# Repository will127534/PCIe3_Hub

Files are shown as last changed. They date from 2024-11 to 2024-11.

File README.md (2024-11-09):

# RPI5 PCIe 3.0 Hub
An opensource PCIe 3.0 Hub design based on ASM2806 with Raspberry Pi 5's PCIe FPC connector design

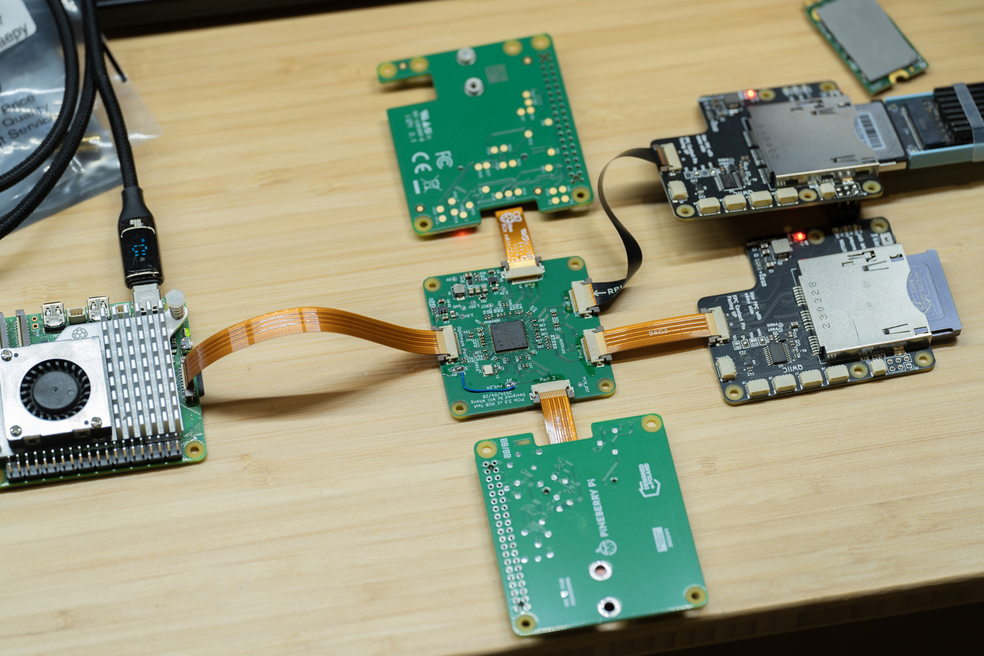
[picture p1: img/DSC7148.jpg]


## Important note

ASM2806A != ASM2806, this design is using ASM2806 specifically.

## Introduction

So basically this is the follow-up on [this](https://www.willwhang.dev/Solar-eclipse-2024/#pcie-30-hub-development), that I finally found a schematic containing how to use [ASM2806](https://www.asmedia.com.tw/product/012Yq70sX2zI9xN5/7c5YQ79xz8urEGr1), which is a PCIe 3.0 hub with x2 upstream and four x1 downstream.  

The board is designed to give that schematic a try, so it is not really designed like those PCIe 2.0 NVMe hub RPi hat designs you might have seen before. Its design is to make my life easier when debugging/soldering it. (i.e single sided components + 5cm x 5cm board size).

Also, because I'm going to build a few boards for RPi5 that I want to have a PCIe 3.0 hub with, all the PCIe connectors on board are the same as RPi’s PCIe FPC "[standard](https://datasheets.raspberrypi.com/pcie/pcie-connector-standard.pdf)", and the testing is also done on RPi5.

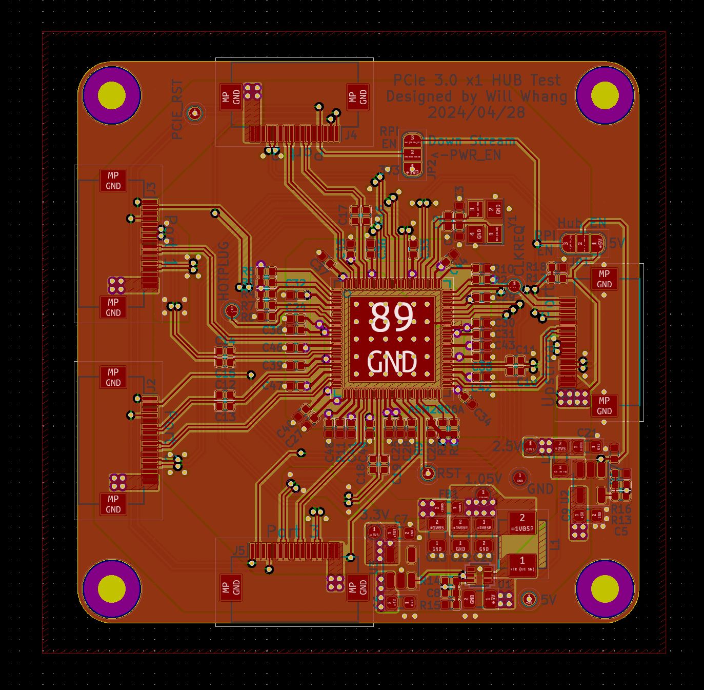
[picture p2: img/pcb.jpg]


Is it working? Yeap!

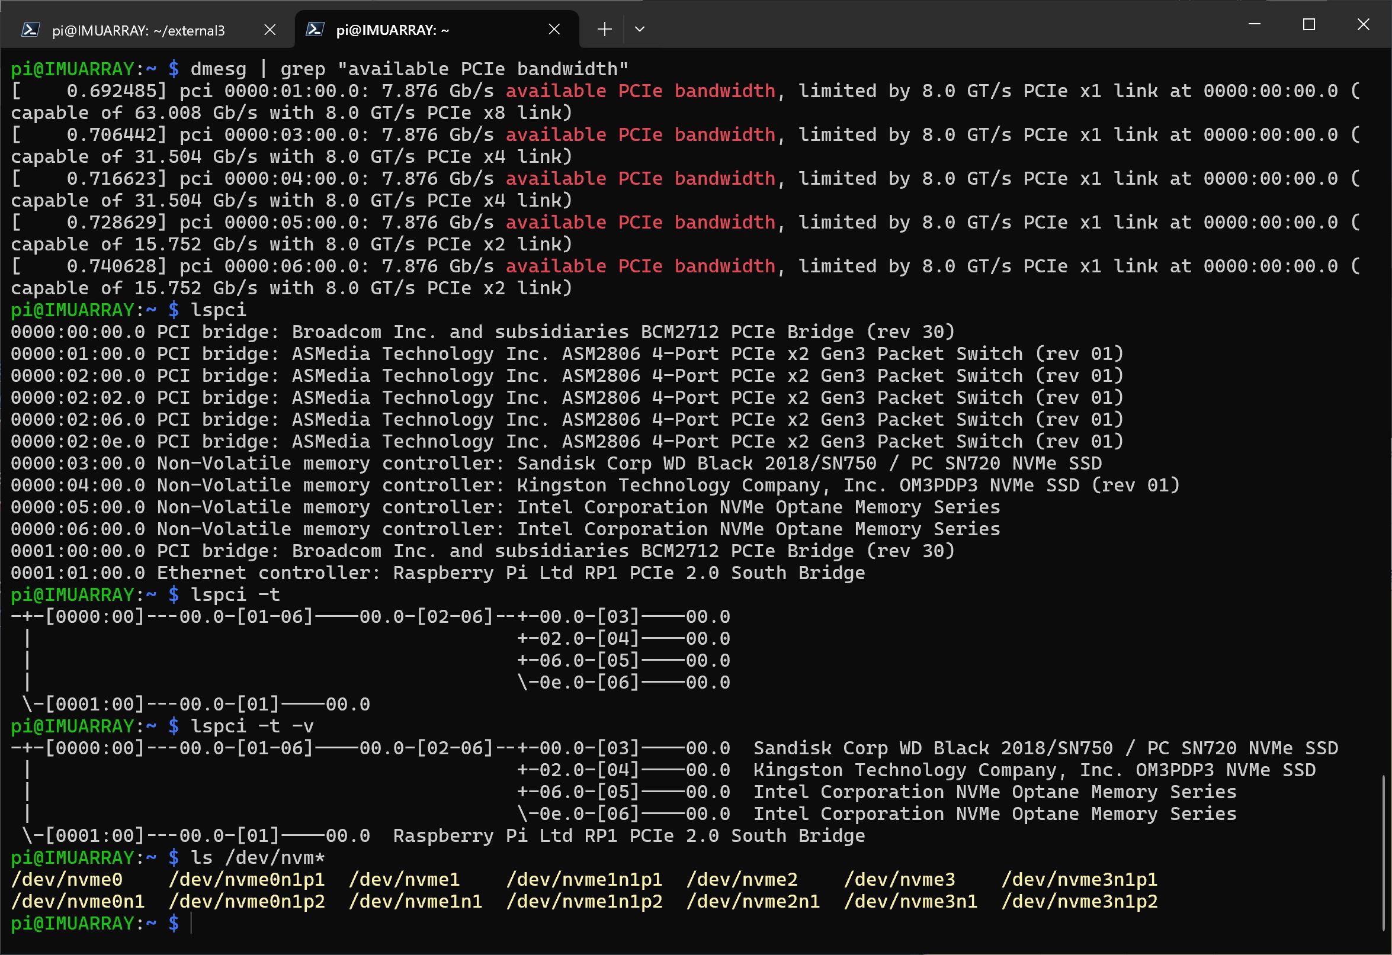
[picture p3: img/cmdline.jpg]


## Detailed notes

So if you compare the PCB files here and the one in the photo, you can see that there is a jump wire in the photo. At the same time, if you look at the PCB files, there are two jumper JP1 and JP2. This is because RPI5 FPC has a power enable signal, where the device should use this signal to power down and up. However, this makes the debugging (checking rail voltage) process slightly difficult, so the jumper here is for forcing ASM2806/downstream device power on. JP1 is for ASM2806 power enable signal, either connect it directly to 5V or using the RPI enable signal. JP2 is the downstream PCIe FPC power enable signal, and it is either 3.3V or RPI enable signal. The one shown in the photo has the downstream PCIe FPC power enable signal bodge wired to the RPI enable signal, and that has been fixed in the PCB file here on GitHub.

For ASM2806, it is configured as four downstream ports with each getting x1 PCIe 3.0. Both upstream clock and downstream clock are based on 100Mhz PCIe clock. No SPI flash is required to function (thankfully). It requires three voltages: 3.3V/2.5V/1.05V. Most of the DC-DC converter here is just grabbing the design/parts I have on my hand and are overspec a bit so you can change it for sure. For the rail naming, there is also 3.3V suspend, but I connected it to 3.3V directly, and the 1.05V I'm following the schematic to add some filtering.

Surprisingly, it doesn't take that much power. As you can see in the power consumption table in the schematic, I can stress test without a heatsink for hours, but the chip does get hot to touch. If that worries you, then you might have to consider adding a small heatsink, especially if the PCB copper is not large enough to dissipate the heat.

There are some signals that I'm interested in, specifically the HOTPLUG signal, and it is attached to a test pad, but I'm not able to see it function by pulling this pin up or down.

Finally, the thing that caught me during the test is how the schematic connects the crystal. In the schematic, there is a 10pf cap on the XO/XI pins, which I'm still quite puzzled about (Normally, I expect to see like a 1M ohm resistor across for the Crystal driver), but it is necessary to have this chip work.

## Performance

Yes, each PCIe downstream device independently can consume up to PCIe 3.0 x1 speed, but once you have more than one going, I’m surprised the bandwidth doesn't seem to be equally shared. I'm not quite sure if that is caused by the tool I use to stress test (four NVMe drives + FIO), or is it caused by the NVMe drive itself (maximum supported MPS). Following Jeff Geerling's [guide](https://www.jeffgeerling.com/blog/2021/getting-faster-10-gbps-ethernet-on-raspberry-pi) I've also enabled pci=pcie_bus_perf and the hub can support up to 512 byte MPS also:

```
[    0.752521] pci 0000:00:00.0: Max Payload Size set to  512/ 512 (was  128), Max Read Rq  512
[    0.752532] pci 0000:01:00.0: Max Payload Size set to  512/ 512 (was  128), Max Read Rq  512
[    0.752543] pci 0000:02:00.0: Max Payload Size set to  512/ 512 (was  128), Max Read Rq  512
[    0.752558] pci 0000:03:00.0: Max Payload Size set to  512/ 512 (was  128), Max Read Rq  512
[    0.752568] pci 0000:02:02.0: Max Payload Size set to  512/ 512 (was  128), Max Read Rq  512
[    0.752588] pci 0000:04:00.0: Max Payload Size set to  128/ 128 (was  128), Max Read Rq  128
[    0.752598] pci 0000:02:06.0: Max Payload Size set to  512/ 512 (was  128), Max Read Rq  512
[    0.752616] pci 0000:05:00.0: Max Payload Size set to  256/ 256 (was  128), Max Read Rq  256
[    0.752627] pci 0000:02:0e.0: Max Payload Size set to  512/ 512 (was  128), Max Read Rq  512
[    0.752644] pci 0000:06:00.0: Max Payload Size set to  256/ 256 (was  128), Max Read Rq  256
```

## Footnotes
* [Interactive BOM](https://htmlpreview.github.io/?https://github.com/will127534/PCIe3_Hub/blob/main/bom/ibom.html) [(provided by InteractiveHtmlBom)
](https://github.com/openscopeproject/InteractiveHtmlBom)
* designed with Kicad v8.0
* Please refrain from inquiring about the source of the chip. Additionally, please note that this chip is quite expensive (approximately 15-20 USD), which is one of the reasons why you may not have encountered any PCIe 3.0 hubs for RPi5 other than this one.

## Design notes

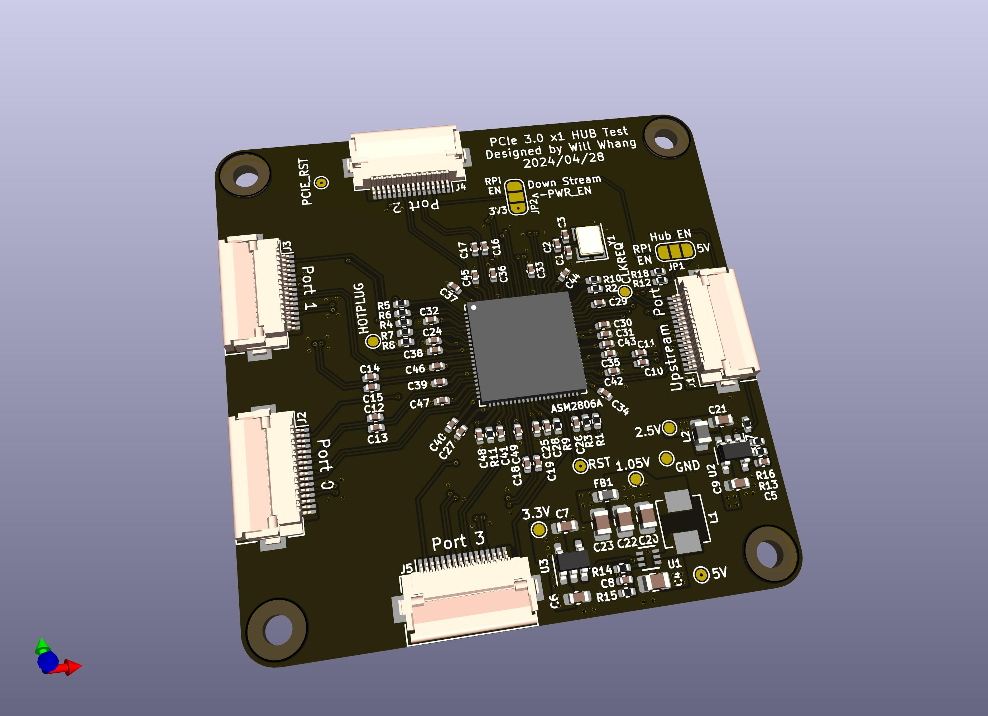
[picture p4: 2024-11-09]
img/3d.jpg

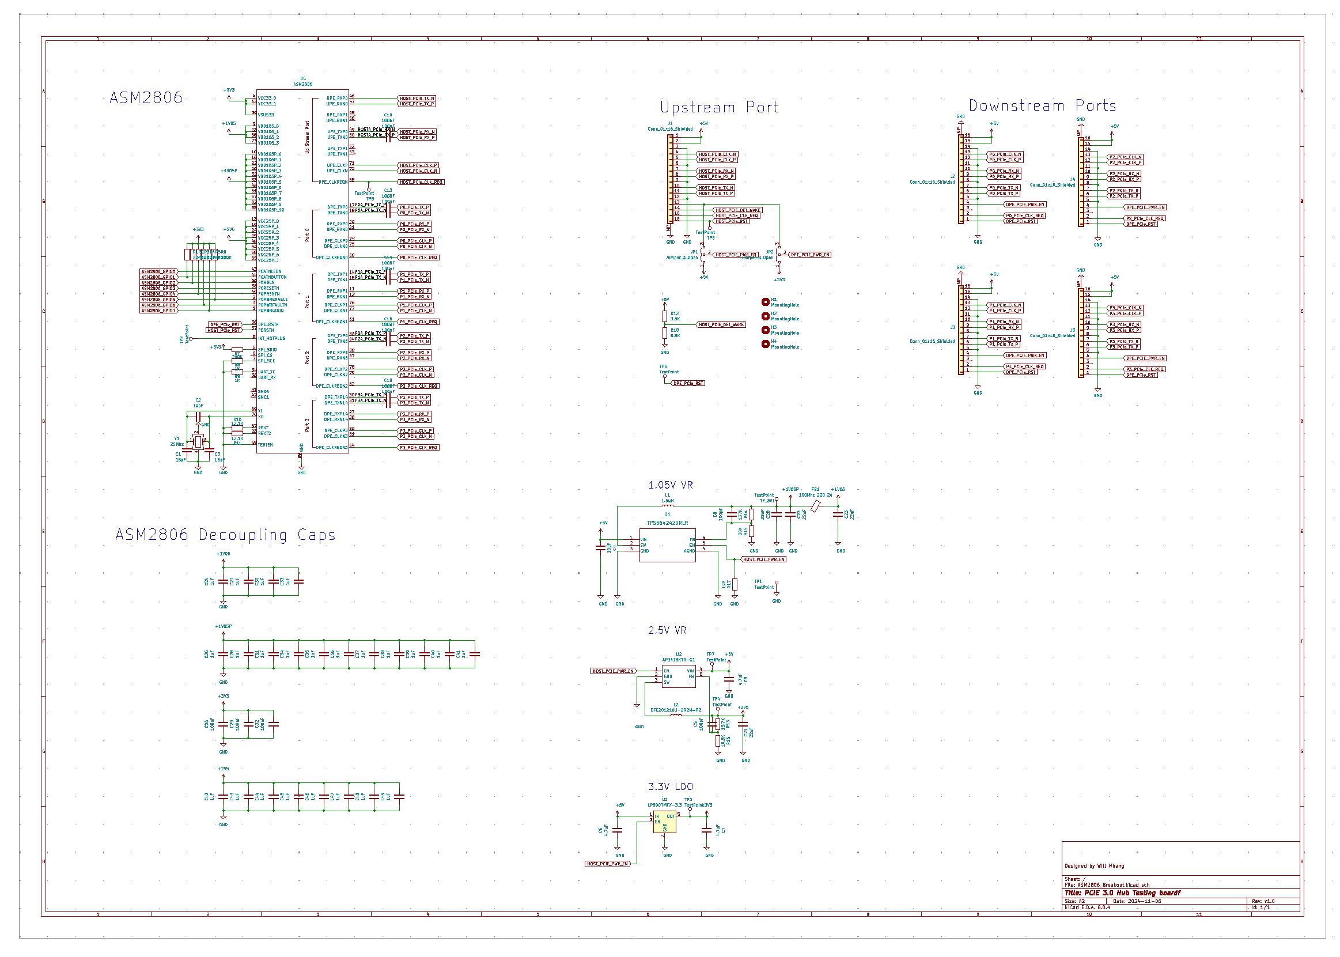
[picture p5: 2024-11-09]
img/sch.jpg

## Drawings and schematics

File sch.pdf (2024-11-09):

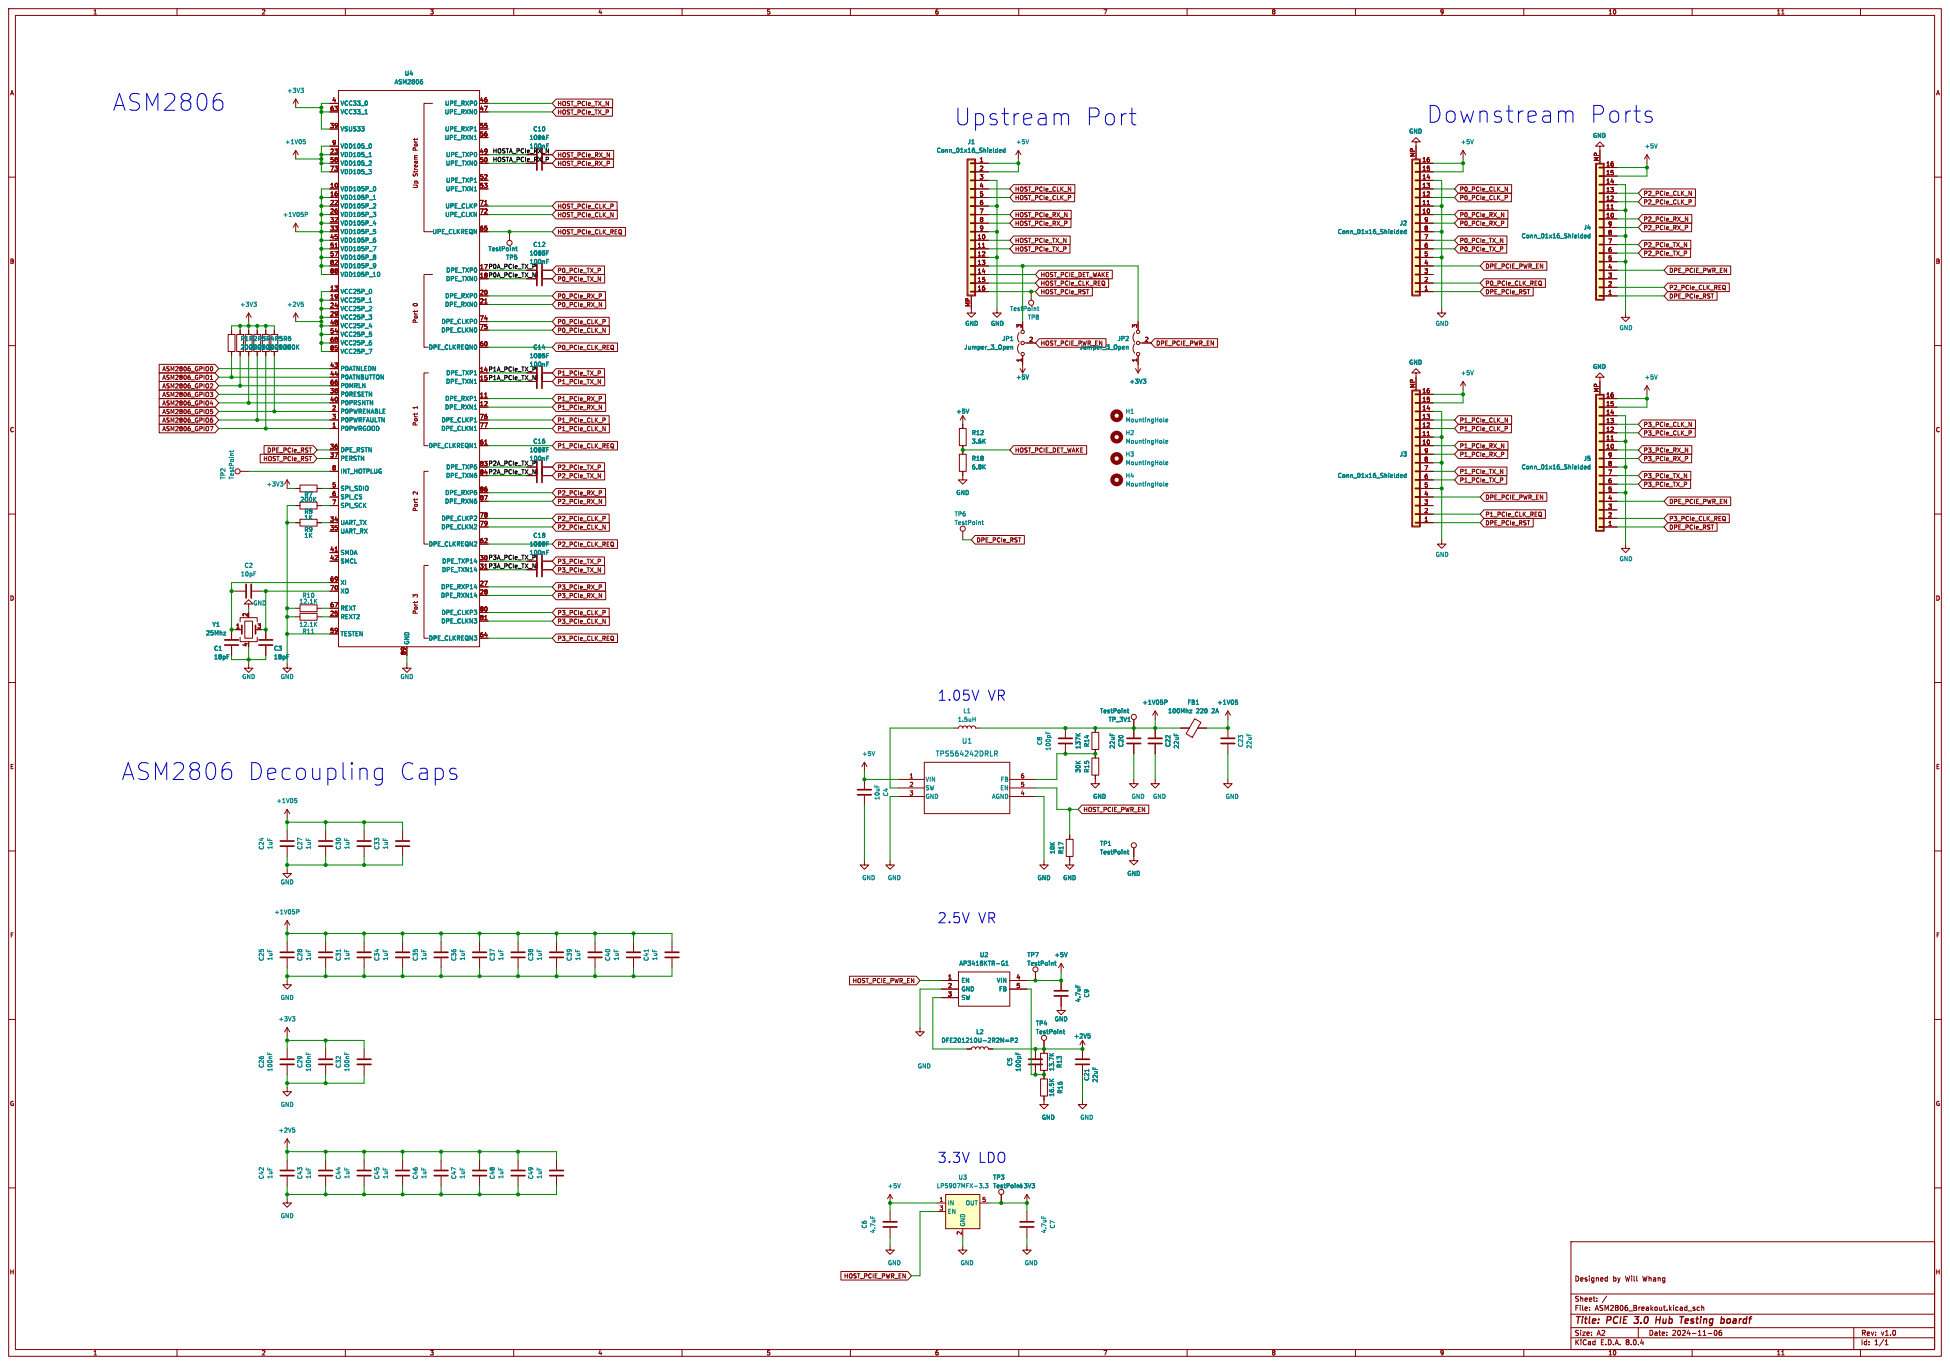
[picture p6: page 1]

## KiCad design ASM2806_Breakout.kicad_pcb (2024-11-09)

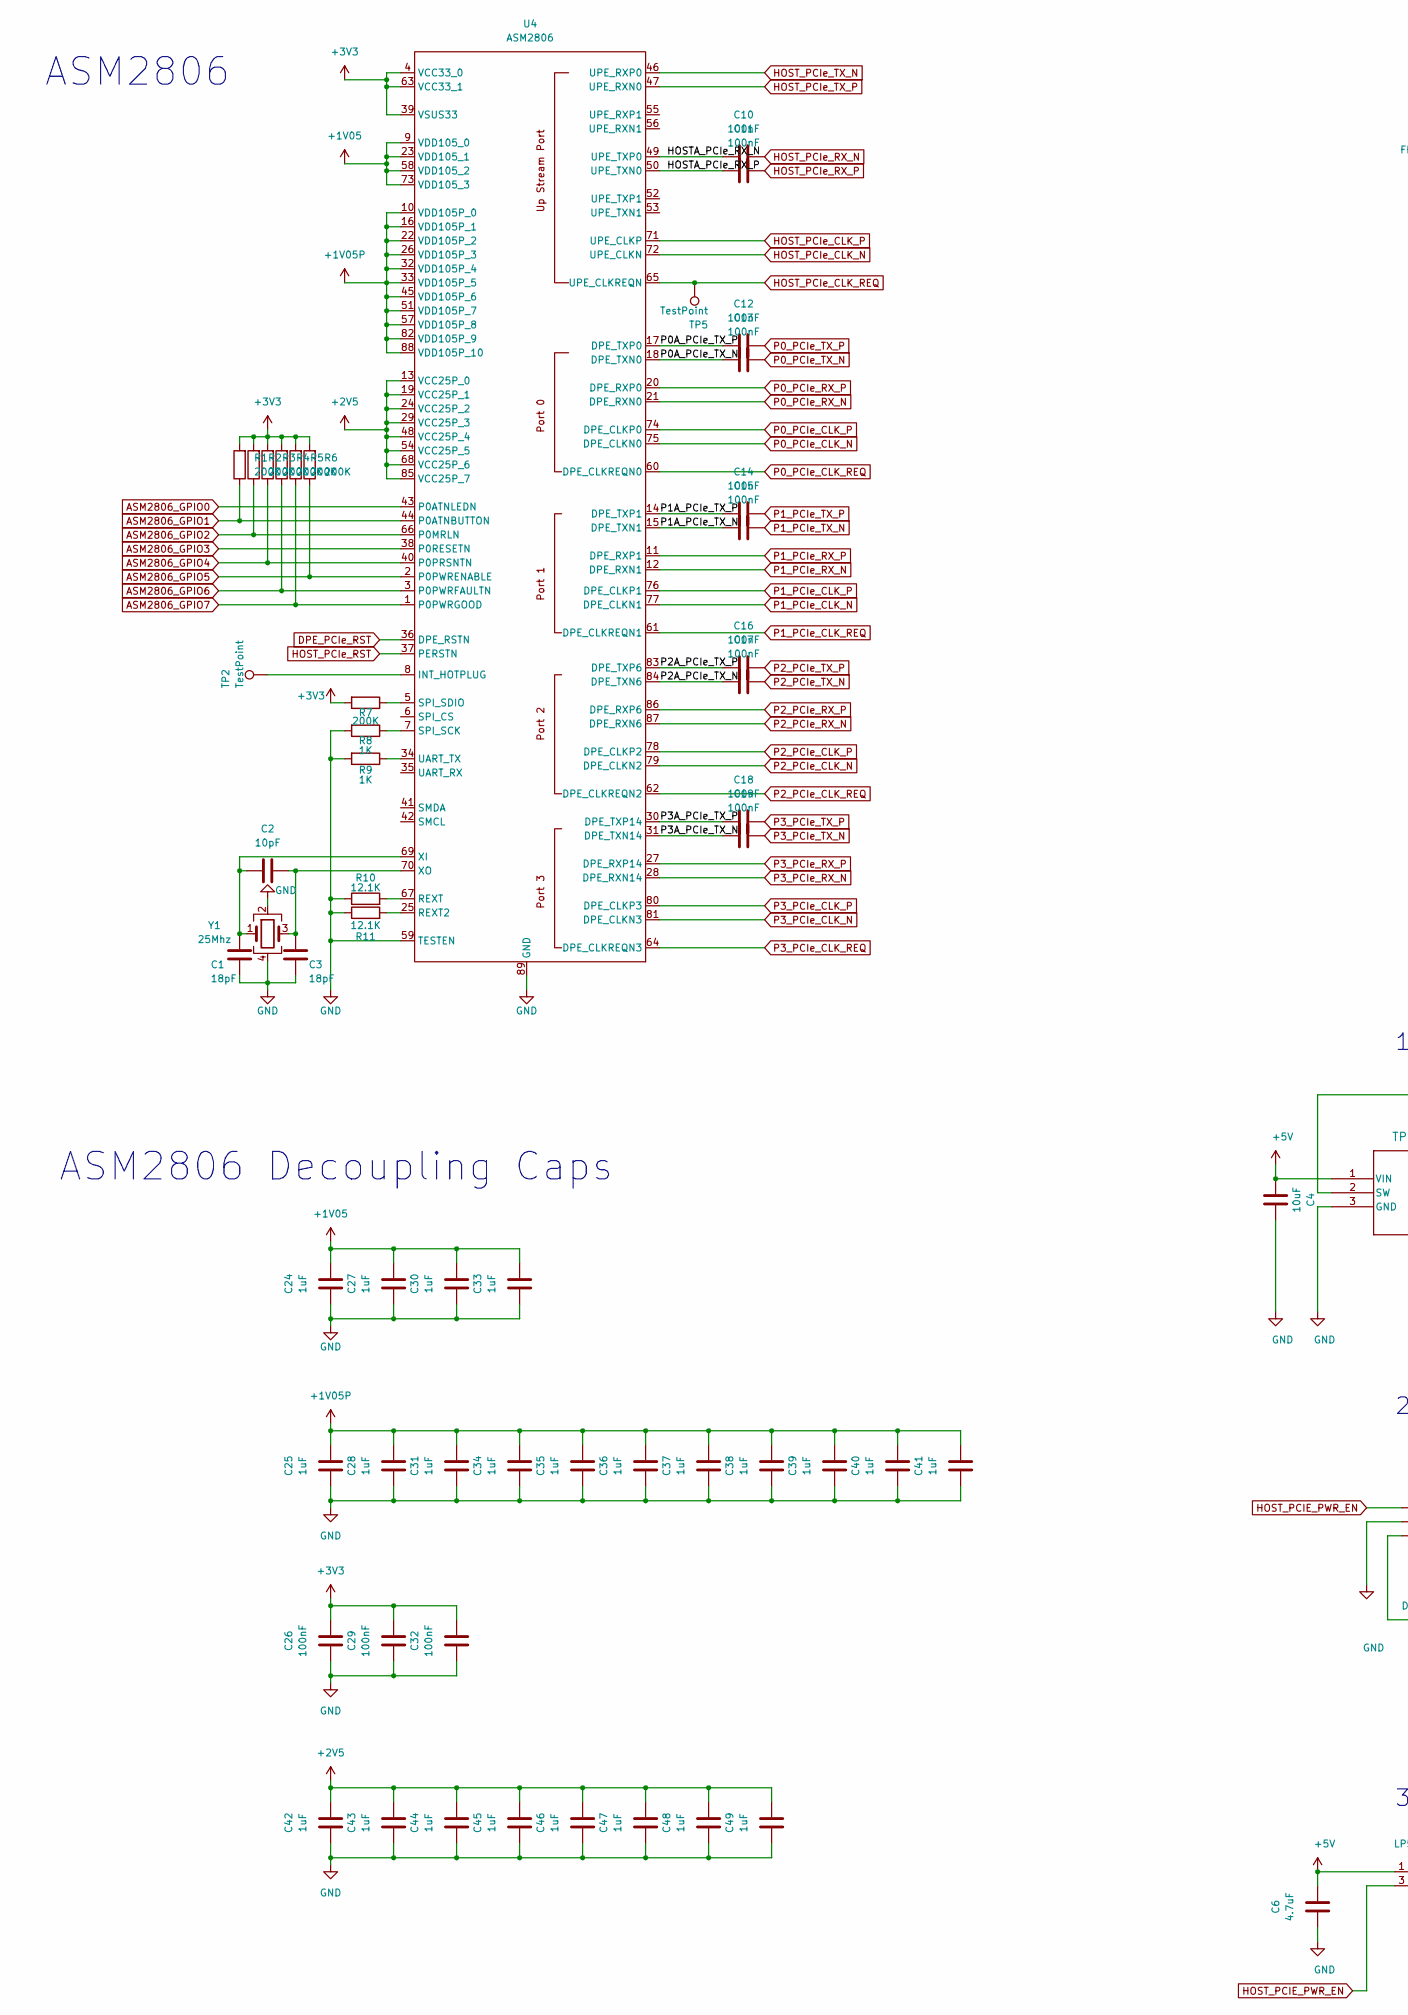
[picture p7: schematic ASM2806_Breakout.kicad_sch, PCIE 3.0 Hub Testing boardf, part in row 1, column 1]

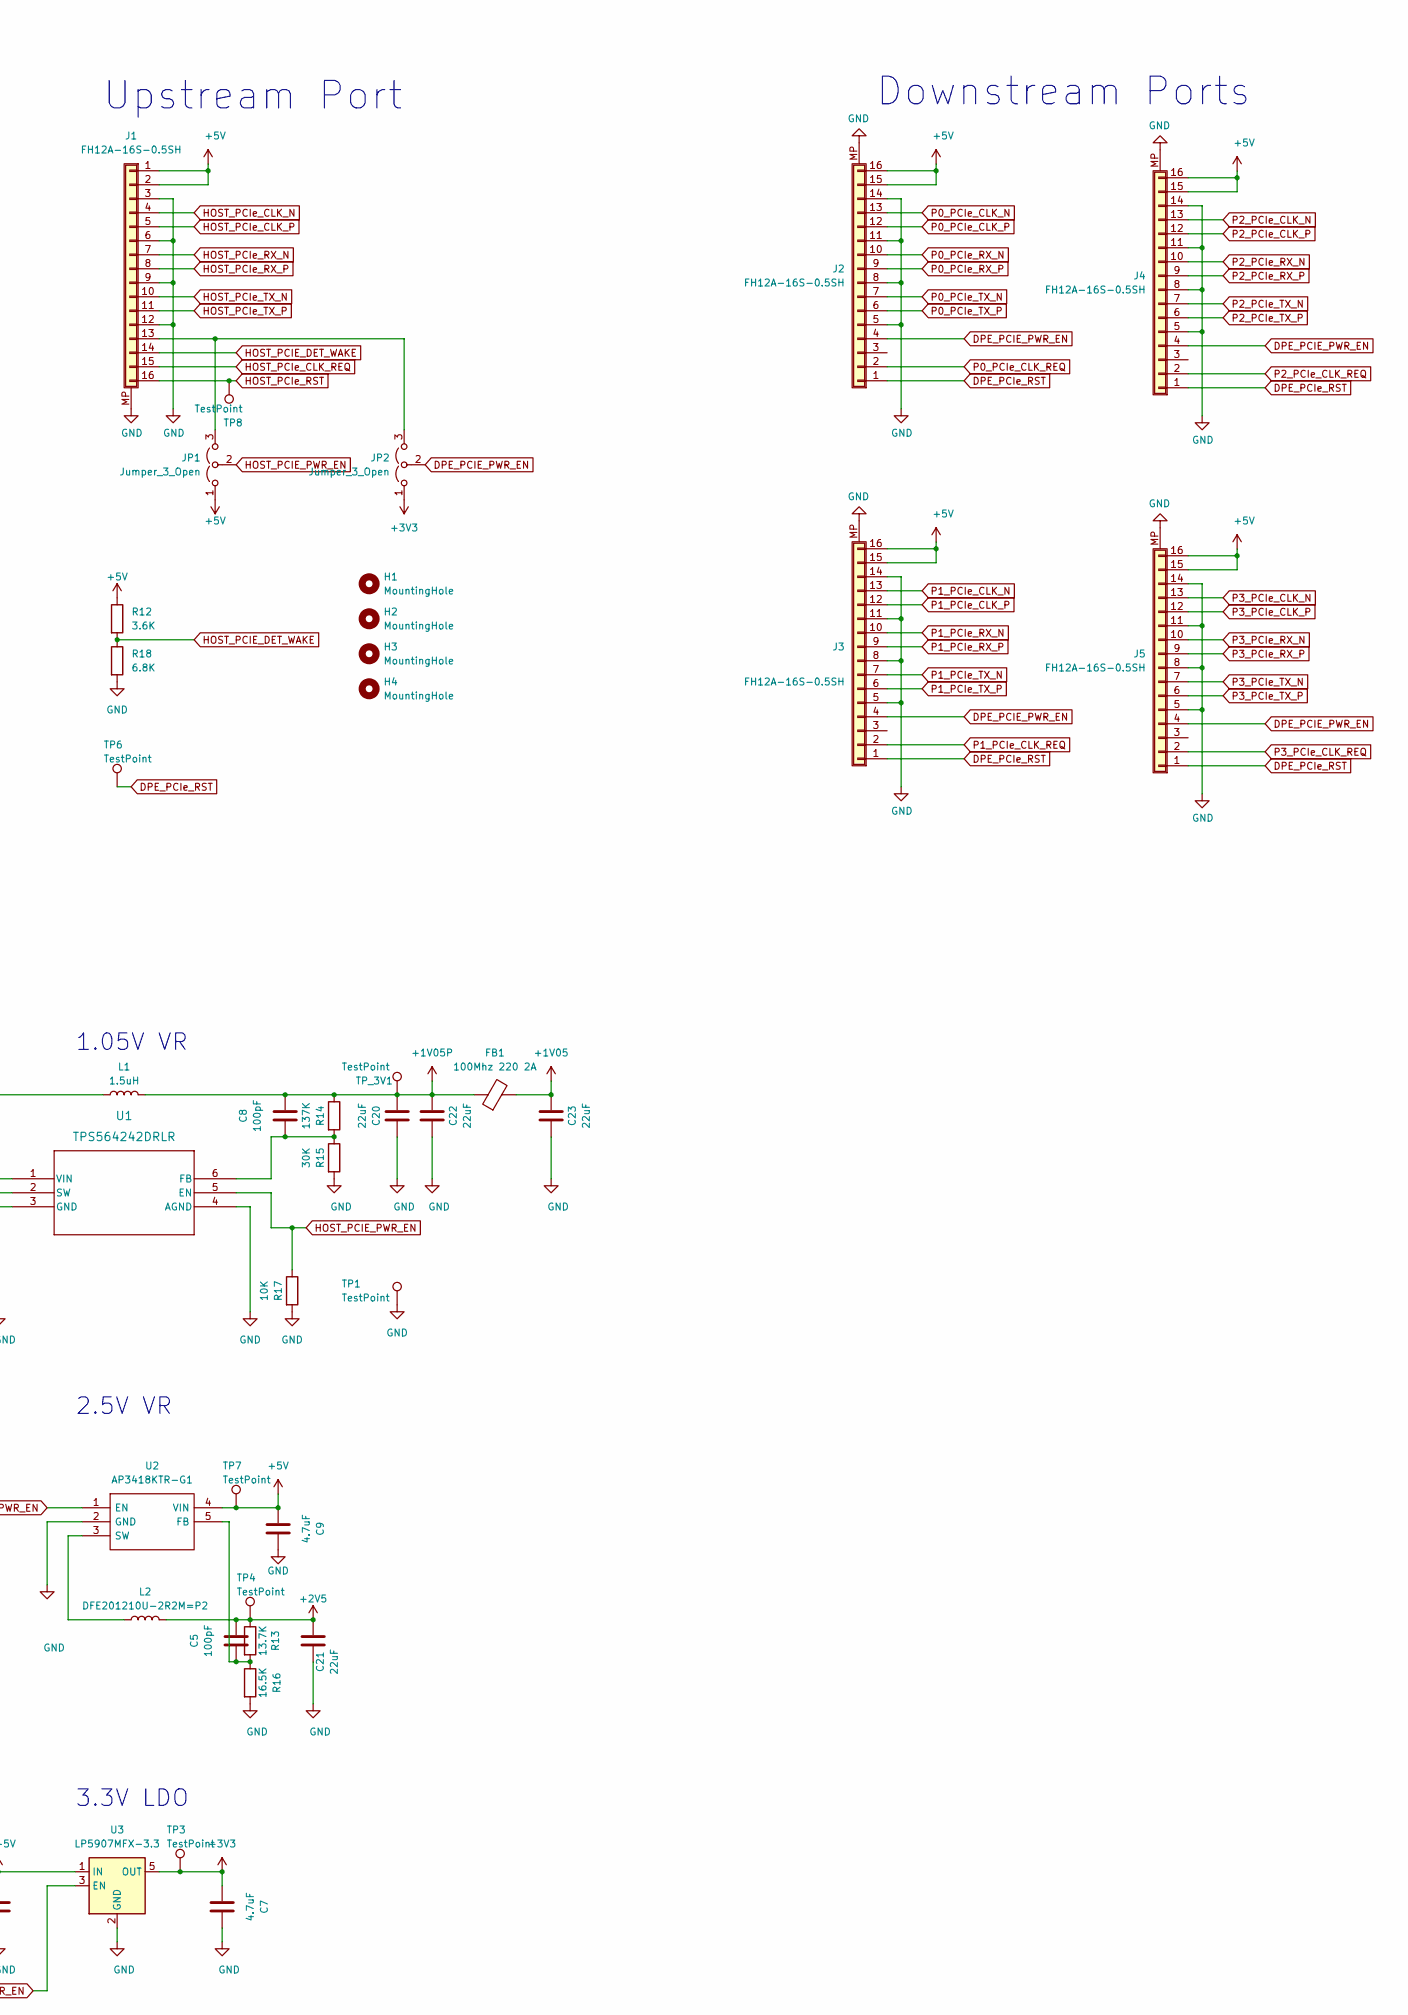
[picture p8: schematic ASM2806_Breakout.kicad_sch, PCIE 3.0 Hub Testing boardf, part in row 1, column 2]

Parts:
C1, C3: 18pF; C_0402_1005Metric
C2: 10pF; C_0402_1005Metric
C4: 10uF; C_0805_2012Metric
C5, C8: 100pF; C_0402_1005Metric
C6, C7, C9: 4.7uF; C_0603_1608Metric
C10, C11, C12, C13, C14, C15, C16, C17, C18, C19, C26, C29, C32: 100nF; C_0402_1005Metric
C20, C22, C23: 22uF; C_0805_2012Metric
C21: 22uF; C_0603_1608Metric
C24, C25, C27, C28, C30, C31, C33, C34, C35, C36, C37, C38, C39, C40, C41, C42, C43, C44, C45, C46, C47, C48, C49: 1uF; C_0402_1005Metric
FB1: 100Mhz 220 2A; L_0603_1608Metric
H1, H2, H3, H4: MountingHole; MountingHole_2.5mm
J1, J2, J3, J4, J5: FH12A-16S-0.5SH; Hirose_FH12-16S-0.5SH_1x16-1MP_P0.50mm_Horizontal
JP1, JP2: Jumper_3_Open; SolderJumper-3_P1.3mm_Open_RoundedPad1.0x1.5mm_NumberLabels
L1: 1.5uH; L_Vishay_IHLP-1616
L2: DFE201210U-2R2M=P2; L_0805_2012Metric
R1, R2, R3, R4, R5, R6, R7: 200K; R_0402_1005Metric
R8, R9: 1K; R_0402_1005Metric
R10, R11: 12.1K; R_0402_1005Metric
R12: 3.6K; R_0402_1005Metric
R13: 13.7K; R_0402_1005Metric
R14: 137K; R_0402_1005Metric
R15: 30K; R_0402_1005Metric
R16: 16.5K; R_0402_1005Metric
R17: 10K; R_0402_1005Metric
R18: 6.8K; R_0402_1005Metric
TP1, TP2, TP3, TP4, TP5, TP6, TP7, TP8: TestPoint; TestPoint_Pad_D1.0mm
TP_3V1: TestPoint; TestPoint_Pad_D1.0mm
U1: TPS564242DRLR; TPS564242DRLR_TEX
U2: AP3418KTR-G1; SOT-23-5; Mouser Part Number 621-AP3418KTR-G1
U3: LP5907MFX-3.3; SOT-23-5
U4: ASM2806; QFN-88_EP_10x10_Pitch0.4mm
Y1: 25Mhz; Crystal_SMD_Abracon_ABM8G-4Pin_3.2x2.5mm

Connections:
+1V05: C23.2, C24.2, C27.2, C30.2, C33.2, FB1.2, U4.9 (VDD105_0), U4.23 (VDD105_1), U4.58 (VDD105_2), U4.73 (VDD105_3)
+1V05P: C8.2, C20.1, C22.2, C25.2, C28.2, C31.2, C34.2, C35.2, C36.2, C37.2, C38.2, C39.2, C40.2, C41.2, FB1.1, L1.2, R14.1, TP_3V1.1, U4.10 (VDD105P_0), U4.16 (VDD105P_1), U4.22 (VDD105P_2), U4.26 (VDD105P_3), U4.32 (VDD105P_4), U4.33 (VDD105P_5), U4.45 (VDD105P_6), U4.51 (VDD105P_7), U4.57 (VDD105P_8), U4.82 (VDD105P_9), U4.88 (VDD105P_10)
+2V5: C5.2, C21.2, C42.2, C43.2, C44.2, C45.2, C46.2, C47.2, C48.2, C49.2, L2.2, R13.1, TP4.1, U4.13 (VCC25P_0), U4.19 (VCC25P_1), U4.24 (VCC25P_2), U4.29 (VCC25P_3), U4.48 (VCC25P_4), U4.54 (VCC25P_5), U4.68 (VCC25P_6), U4.85 (VCC25P_7)
+3V3: C7.1, C26.2, C29.2, C32.2, JP2.1 (A), R1.2, R2.2, R3.2, R4.2, R5.2, R6.2, R7.2, TP3.1, U3.5 (OUT), U4.4 (VCC33_0), U4.39 (VSUS33), U4.63 (VCC33_1)
+5V: C4.1, C6.2, C9.1, J1.1, J1.2, J2.15, J2.16, J3.15, J3.16, J4.15, J4.16, J5.15, J5.16, JP1.1 (A), R12.1, TP7.1, U1.1 (VIN), U2.4 (VIN), U3.1 (IN)
/HOSTA_PCIe_RX_N: C10.1, U4.49 (UPE_TXP0)
/HOSTA_PCIe_RX_P: C11.1, U4.50 (UPE_TXN0)
/P0A_PCIe_TX_N: C13.1, U4.18 (DPE_TXN0)
/P0A_PCIe_TX_P: C12.1, U4.17 (DPE_TXP0)
/P1A_PCIe_TX_N: C15.1, U4.15 (DPE_TXN1)
/P1A_PCIe_TX_P: C14.1, U4.14 (DPE_TXP1)
/P2A_PCIe_TX_N: C17.1, U4.84 (DPE_TXN6)
/P2A_PCIe_TX_P: C16.1, U4.83 (DPE_TXP6)
/P3A_PCIe_TX_N: C19.1, U4.31 (DPE_TXN14)
/P3A_PCIe_TX_P: C18.1, U4.30 (DPE_TXP14)
ASM2806_GPIO0: U4.43 (P0ATNLEDN)
ASM2806_GPIO1: R1.1, U4.44 (P0ATNBUTTON)
ASM2806_GPIO2: R2.1, U4.66 (P0MRLN)
ASM2806_GPIO3: U4.38 (P0RESETN)
ASM2806_GPIO4: R3.1, U4.40 (P0PRSNTN)
ASM2806_GPIO5: R6.1, U4.2 (P0PWRENABLE)
ASM2806_GPIO6: R4.1, U4.3 (P0PWRFAULTN)
ASM2806_GPIO7: R5.1, U4.1 (P0PWRGOOD)
DPE_PCIE_PWR_EN: J2.4, J3.4, J4.4, J5.4, JP2.2 (C)
DPE_PCIe_RST: J2.1, J3.1, J4.1, J5.1, TP6.1, U4.36 (DPE_RSTN)
GND: C1.2, C3.2, C4.2, C6.1, C7.2, C9.2, C20.2, C21.1, C22.1, C23.1, C24.1, C25.1, C26.1, C27.1, C28.1, C29.1, C30.1, C31.1, C32.1, C33.1, C34.1, C35.1, C36.1, C37.1, C38.1, C39.1, C40.1, C41.1, C42.1, C43.1, C44.1, C45.1, C46.1, C47.1, C48.1, C49.1, J1.3, J1.6, J1.9, J1.12, J1.MP (Shield), J2.5, J2.8, J2.11, J2.14, J2.MP (Shield), J3.5, J3.8, J3.11, J3.14, J3.MP (Shield), J4.5, J4.8, J4.11, J4.14, J4.MP (Shield), J5.5, J5.8, J5.11, J5.14, J5.MP (Shield), R8.2, R9.2, R10.1, R11.1, R15.2, R16.2, R17.2, R18.2, TP1.1, U1.3 (GND), U1.4 (AGND), U2.2 (GND), U3.2 (GND), U4.59 (TESTEN), U4.89 (GND), Y1.2, Y1.4
HOST_PCIE_DET_WAKE: J1.14, R12.2, R18.1
HOST_PCIE_PWR_EN: JP1.2 (C), R17.1, U1.5 (EN), U2.1 (EN), U3.3 (EN)
HOST_PCIe_CLK_N: J1.4, U4.72 (UPE_CLKN)
HOST_PCIe_CLK_P: J1.5, U4.71 (UPE_CLKP)
HOST_PCIe_CLK_REQ: J1.15, TP5.1, U4.65 (UPE_CLKREQN)
HOST_PCIe_RST: J1.16, TP8.1, U4.37 (PERSTN)
HOST_PCIe_RX_N: C10.2, J1.7
HOST_PCIe_RX_P: C11.2, J1.8
HOST_PCIe_TX_N: J1.10, U4.46 (UPE_RXP0)
HOST_PCIe_TX_P: J1.11, U4.47 (UPE_RXN0)
unnamed: J1.13, JP1.3 (B), JP2.3 (B)
unnamed: C8.1, R14.2, R15.1, U1.6 (FB)
unnamed: L1.1, U1.2 (SW)
unnamed: C5.1, R13.2, R16.1, U2.5 (FB)
unnamed: L2.1, U2.3 (SW)
unnamed: TP2.1, U4.8 (INT_HOTPLUG)
unnamed: R11.2, U4.25 (REXT2)
unnamed: R10.2, U4.67 (REXT)
unnamed: R8.1, U4.7 (SPI_SCK)
unnamed: R7.1, U4.5 (SPI_SDIO)
unnamed: R9.1, U4.34 (UART_TX)
unnamed: C1.1, C2.1, U4.69 (XI), Y1.1
unnamed: C2.2, C3.1, U4.70 (XO), Y1.3
P0_PCIe_CLK_N: J2.13, U4.75 (DPE_CLKN0)
P0_PCIe_CLK_P: J2.12, U4.74 (DPE_CLKP0)
P0_PCIe_CLK_REQ: J2.2, U4.60 (DPE_CLKREQN0)
P0_PCIe_RX_N: J2.10, U4.21 (DPE_RXN0)
P0_PCIe_RX_P: J2.9, U4.20 (DPE_RXP0)
P0_PCIe_TX_N: C13.2, J2.7
P0_PCIe_TX_P: C12.2, J2.6
P1_PCIe_CLK_N: J3.13, U4.77 (DPE_CLKN1)
P1_PCIe_CLK_P: J3.12, U4.76 (DPE_CLKP1)
P1_PCIe_CLK_REQ: J3.2, U4.61 (DPE_CLKREQN1)
P1_PCIe_RX_N: J3.10, U4.12 (DPE_RXN1)
P1_PCIe_RX_P: J3.9, U4.11 (DPE_RXP1)
P1_PCIe_TX_N: C15.2, J3.7
P1_PCIe_TX_P: C14.2, J3.6
P2_PCIe_CLK_N: J4.13, U4.79 (DPE_CLKN2)
P2_PCIe_CLK_P: J4.12, U4.78 (DPE_CLKP2)
P2_PCIe_CLK_REQ: J4.2, U4.62 (DPE_CLKREQN2)
P2_PCIe_RX_N: J4.10, U4.87 (DPE_RXN6)
P2_PCIe_RX_P: J4.9, U4.86 (DPE_RXP6)
P2_PCIe_TX_N: C17.2, J4.7
P2_PCIe_TX_P: C16.2, J4.6
P3_PCIe_CLK_N: J5.13, U4.81 (DPE_CLKN3)
P3_PCIe_CLK_P: J5.12, U4.80 (DPE_CLKP3)
P3_PCIe_CLK_REQ: J5.2, U4.64 (DPE_CLKREQN3)
P3_PCIe_RX_N: J5.10, U4.28 (DPE_RXN14)
P3_PCIe_RX_P: J5.9, U4.27 (DPE_RXP14)
P3_PCIe_TX_N: C19.2, J5.7
P3_PCIe_TX_P: C18.2, J5.6

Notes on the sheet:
2.5V VR
ASM2806
3.3V LDO
Upstream Port
1.05V VR
ASM2806 Decoupling Caps
Downstream Ports

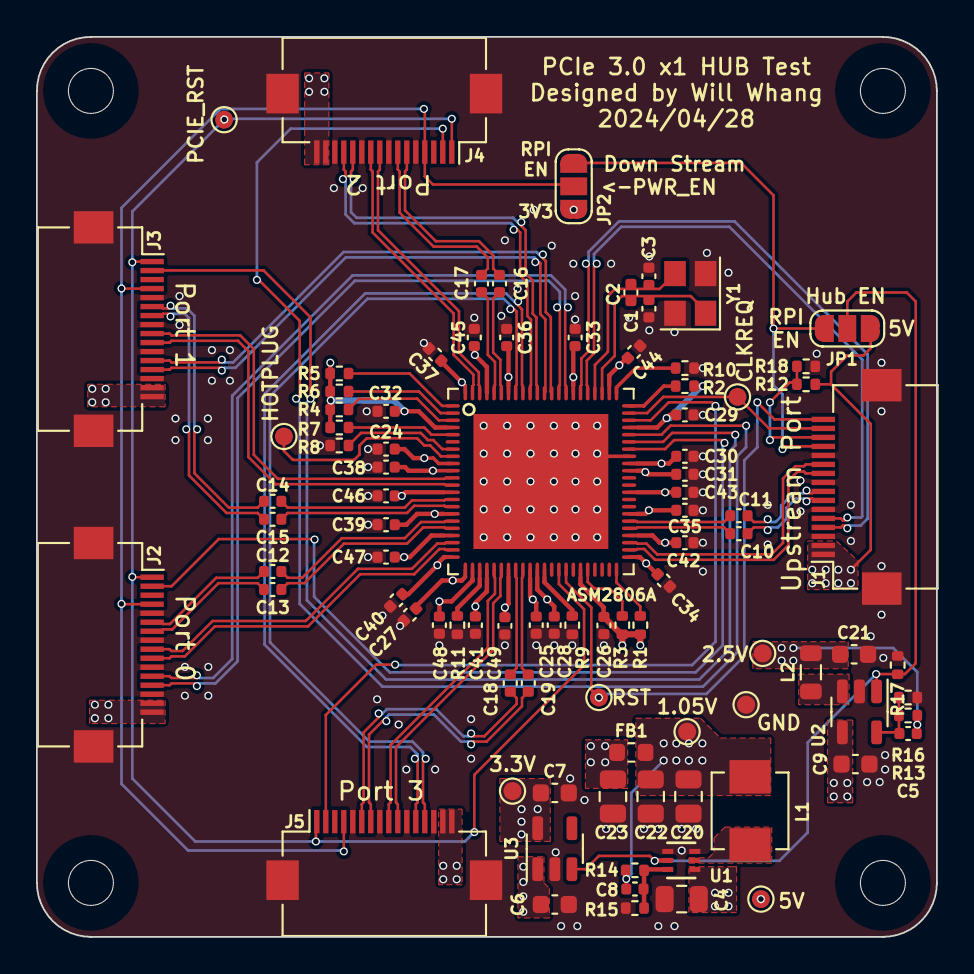
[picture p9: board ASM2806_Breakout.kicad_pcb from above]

Board: 4 copper layers, 50.0 x 50.0 mm, 95 parts (0 on the bottom side), 75 nets.

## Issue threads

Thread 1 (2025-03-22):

SPI flash function

piecol, 2025-03-22:
Hello,

thanks for sharing your designs, really interesting projects!
Sorry for opening an issue, I have some questions:
What is the role of the SPI flash?
How do you know it can be omitted from the design?

I got from the manufacturer the datasheet, but it lacks information on the subject.

Cheers

hutchx86, 2025-06-25:
> hey [@hutchx86](https://github.com/hutchx86), they told me that the flash is needed for proper setup of the hub. I somewhat tried to push a response stating it's not strictly necessary, but failed. So I guess it's a matter of trying. Maybe include a flash chip as DNP for later integration.

I *just*, like, 20 seconds ago got a response from them haha, also just stating that the spi flash is necessary for better compatibility, but the firmware and tool will only be available once some sort of deal is made (which is out of my scope). They did state that dumping the firmware from other boards and just using that isn't a problem (or at least not for them)

hutchx86, 2025-06-25:
> sounds interesting, I'm available for a collaboration! I have a HAT from seeed studio that uese that chip and mounts a flash

Oh, that'd be neat! I'm down too! How best to go about contacting you? I'm under the same name on bsky (and from there we can switch to instant messaging, just don't want to be putting that stuff on a public forum lol

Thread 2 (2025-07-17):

Swapped pins in schen

sdyspb, 2025-07-17:
According to the original schem from Asmedia as well as datasheet, pins number 33 and 73 are swapped in your design. Probably you used the schem with the same bug. These pins are both in 1.05V domain, but their functions are different.
